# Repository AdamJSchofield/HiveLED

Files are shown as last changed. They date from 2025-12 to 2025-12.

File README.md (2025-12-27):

# HiveLED

Hexagonal LED matrix display with 107 individually addressable LEDs (SK9822-A), onboard ESP32-S3 MCU, buck converter, current/temperature monitoring, and PWM fan headers with 40x80mm board area reserved for an optional heatsink. Designed to be compatible with WLED. Multiple panels can be chained together and driven by a single 9-24V power supply. LED display input can be controlled by the onboard MCU, received over a network, or hard wired with onboard JST connectors.

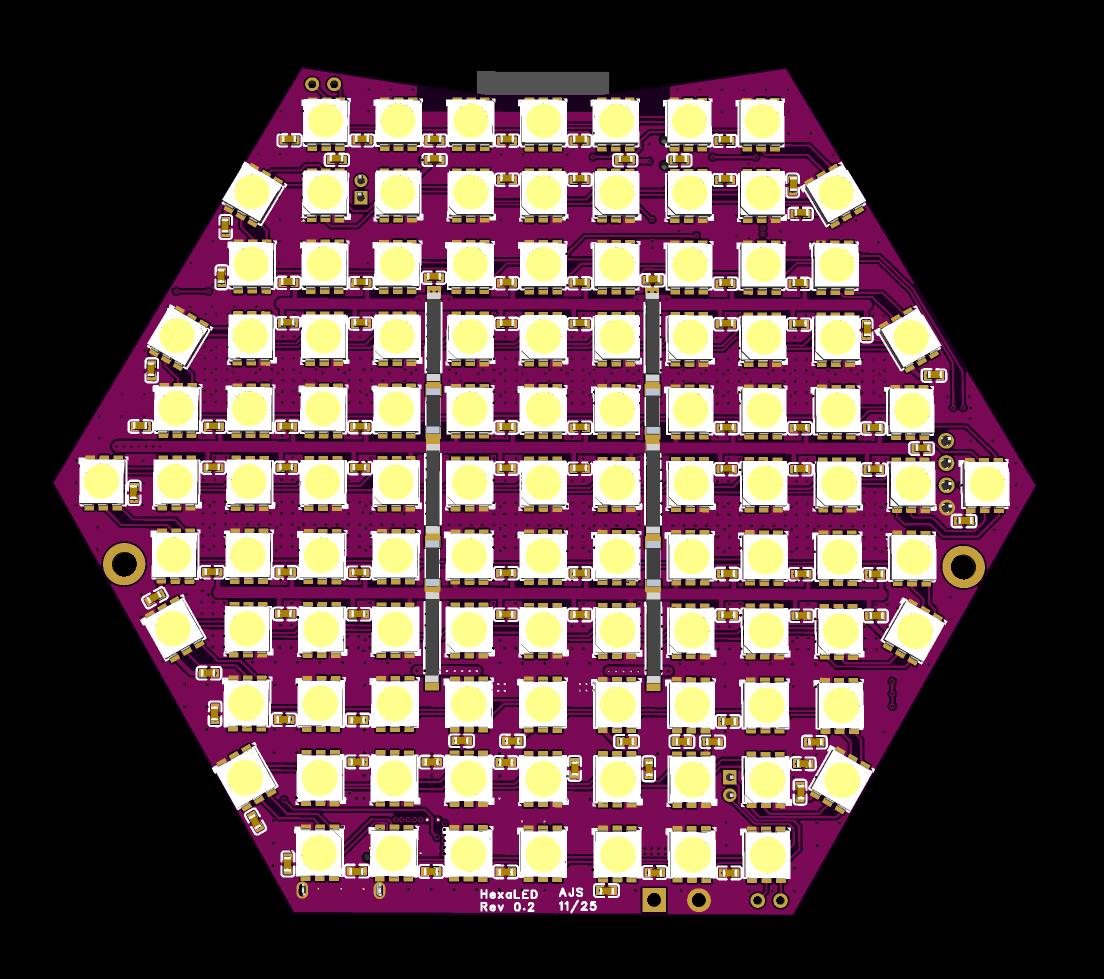
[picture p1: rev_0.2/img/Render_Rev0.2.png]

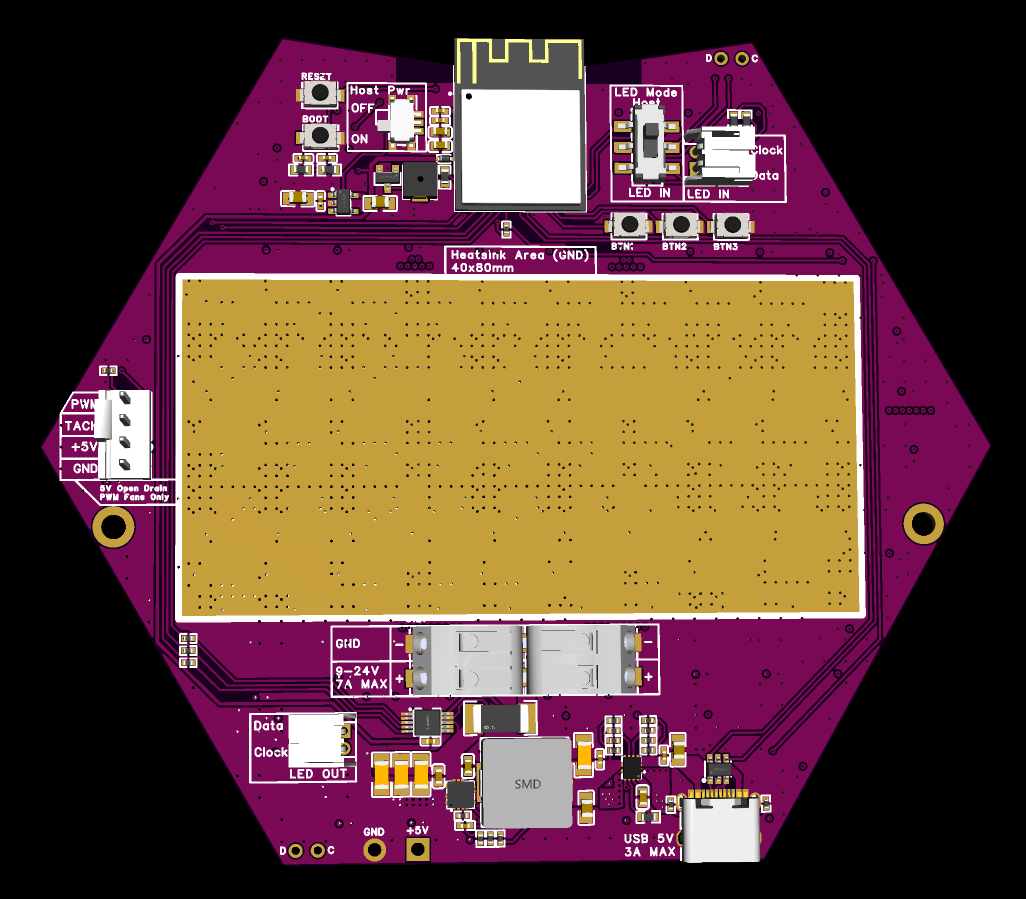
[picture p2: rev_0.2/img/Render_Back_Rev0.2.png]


## Specs
- 107x SK9822-A LEDs (max 55mA each)
- Max power consumption: 28W
- Min input voltage: 9V
- Max input voltage: 24V

## Warning

Dense LED matrix displays like this one have the potential to generate A LOT of heat. With all safety limits disabled at full brightness, these LEDs can produce enough heat to cause a catastrophic meltdown.

Managing Heat:
- Use the "Current Limiter" feature of WLED. 2000mA is a reasonable limit. This is only a soft limit for the brightness control based on estimated current by WLED. The brightness slider in WLED is scaled by a factor of ```(WLED Current Limit/Potential MAX Current)```. IMPORTANT: The INA228 current displayed in WLED when using the usermod is the current of the input power supply inclusive of all components at the input power supply voltage. The "Estimated Current" in vanilla WLED is only an estimate of the current drawn by the LEDs at 5V. When using a 12V power supply, the estimated current in WLED will indicate higher than the INA228 current because ```Current = Voltage / Resistance (load)```, often defined as V=IR.
- Use the INA228 Usermod and configure emergency shutoff based on over-temperature or over-power conditions. 70C is a good temperature limit for enclosures printed in PETG. 
- Use a 5V PWM fan and 40x80mm heatsink to dissipate heat more effectivley. The recommended fan is a Noctua NF-A4x10 5V PWM. One, or two with a 4-pin splitter. 40x40mm or 40x80mm heatsinks are commonly available online. A PWM fan and aluminum heatsink can reduce the max temperature of the board at 50% brightness by 15C. This can help extend the life of the LEDs or enable higher current/brightness limits.

## WLED Setup

https://kno.wled.ge/

### LED Settings

- LED Type: APA102 (similar timings to SK9822)
- Clock Speed: Fastest
- Num LEDs: 107
- Data Pin: 35
- Clock Pin: 36
- Button 1 Pin: 47
- Button 2 Pin: 33
- Button 3 Pin: 34

### INA228 Usermod
The HiveLED matrix contains an onboard INA228 IC for monitoring the temperature of the PCB and real-time power consumption. These features provide additional diagnostic information and can be used as an electronic fuse as a backup to the "soft" current limiter built into WLED. These features also enable automatic temperature control with a 5V PWM fan and optional heatsink. Accurate temperature monitoring and configurable emergency shutoff functions protect the (most likely 3D printed) enclosure, extend the life of the components, and reduce the risk of catastrophic failure.

I will submit a pull request to add the INA228 usermod to WLED soon. To build your own binaries that include support for the INA228 features, see my fork of the WLED repo.

### Usermod Pin Settings

Config > Usermods

- Global I2C SDA Pin: 15
- Global I2C SCL Pin: 14
- INA228 Alert Pin: 16
- Fan PWM Pin: 12
- Fan Tach Pin: 13
- Buzzer Pin: 9

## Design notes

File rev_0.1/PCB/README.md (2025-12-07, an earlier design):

## Description
A bare-bones hexagon-shaped LED panel with recillinear LED spacing. Uses SK9822-A LEDS in a 4-wire serial configuration and serpentine routing. Can be manufactured with a single copper layer on PCB materials such as aluminum for better heat dissipation. Clock and Data input pins are positioned at the top of the board with daisy-chainable outputs at the bottom. Similarly, there are two contacts for 5V and GND on each end of the board.

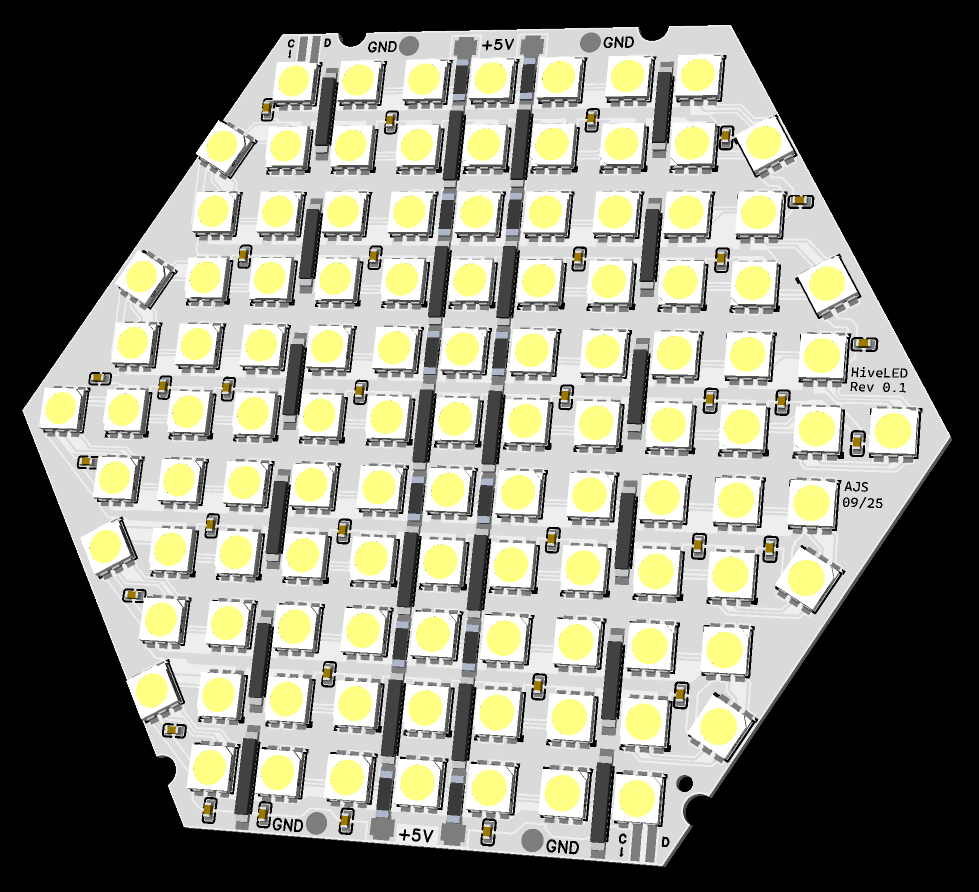
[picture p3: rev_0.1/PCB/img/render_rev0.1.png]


## Specifications
- 107x SK9822-A LEDs
- 5V operating voltage
- 2mm-pitch solderable pads for Clock and Data signal lines (input and output)
- 0-ohm jumpers for clean power traces and low-impedence return path to ground

## Caution
With all onboad LEDs set to full bright white, the total current draw of the panel can be up to 5.5A! Even on aluminium substrate, this is far too much power for the small board to dissipate safely. 5V fans or heatsinks can be attached to the back of the aluminum board for better heat distribution and the ability to run brighter for longer without overheating.

Use caution and limit the current draw to 2-3A in firmware when possible and avoid running the LEDs at full white for extended periods. Always use a physical fuse (2-3A) on the input power supply line to prevent hardware failures or firmware glitches from exceeding the recomended current draw and safety margins.

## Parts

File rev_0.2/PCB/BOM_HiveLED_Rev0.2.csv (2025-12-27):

No. | Quantity | Comment | Designator | Footprint | Value | Manufacturer Part | Manufacturer | Supplier Part | Supplier
1 | 5 | TS-1088-AR02016 | BOOT,BTN1,BTN2,BTN3,RESET | SW-SMD_L3.9-W3.0-P4.45 |  | TS-1088-AR02016 | XUNPU(讯普) | C720477 | LCSC
2 | 1 | 4kHz | BUZZER1 | BUZ-SMD_L4.0-W4.0-P3.50-L | 4kHz | FUET-4020 | FUET(福声科技) | C391027 | LCSC
3 | 97 | 1uF | C1,C2,C3,C4,C5,C6,C7,C8,C9,C10,C11,C12,C13,C14,C15,C16,C17,C18,C19,C20,C21,C22,C23,C24,C25,C26,C27,C28,C30,C31,C33,C34,C35,C36,C37,C38,C39,C41,C42,C44,C45,C46,C47,C48,C49,C50,C51,C53,C54,C56,C57,C58,C59,C60,C61,C62,C63,C64,C66,C67,C69,C70,C71,C72,C73,C74,C75,C77,C79,C80,C82,C83,C84,C85,C86,C87,C88,C89,C90,C91,C92,C93,C94,C95,C96,C97,C98,C99,C100,C101,C102,C103,C104,C105,C106,C107,C143 | C0603 | 1uF | CL10B105KA8NNNC | SAMSUNG(三星) | C29936 | LCSC
4 | 4 | 10uF | C108,C109,C155,C156 | C0805 | 10uF | CL21B106KOQNNNE | SAMSUNG(三星) | C95841 | LCSC
5 | 2 | 10uF | C112,C113 | C0603 | 10uF | CL10A106MA8NRNC | SAMSUNG(三星) | C96446 | LCSC
6 | 1 | 1uF | C114 | C0402 | 1uF | CL05A105KA5NQNC | SAMSUNG(三星) | C52923 | LCSC
7 | 2 | 100nF | C115,C119 | C0402 | 100nF | CL05B104KO5NNNC | SAMSUNG(三星) | C1525 | LCSC
8 | 1 | 1uF | C118 | C0402 | 1uF | CL05A105KO5NNNC | SAMSUNG(三星) | C29266 | LCSC
9 | 4 | 100nF | C136,C153,C154,C157 | C0402 | 100nF | CL05B104KB54PNC | SAMSUNG(三星) | C307331 | LCSC
10 | 3 | 4.7uF | C146,C147,C148 | C1206 | 4.7uF | 1206B475K500NT | FH(风华) | C29823 | LCSC
11 | 2 | 100nF | C149,C150 | C0603 | 100nF | CC0603KRX7R9BB104 | YAGEO(国巨) | C14663 | LCSC
12 | 1 | 47uF | C151 | C1206 | 47uF | CL31A476MPHNNNE | SAMSUNG(三星) | C96123 | LCSC
13 | 1 | 100pF | C152 | C0402 | 100pF | 0402CG101J500NT | FH(风华) | C1546 | LCSC
14 | 1 | 470531000 | CN2 | CONN-TH_47053-1000 |  | 470531000 | MOLEX | C240840 | LCSC
15 | 1 | RB521S30T1G | D4 | SOD-523_L1.2-W0.8-LS1.6-RD |  | RB521S30T1G | onsemi(安森美) | C145179 | LCSC
16 | 1 | USBLC6-2SC6 | D5 | SOT-23-6_L2.9-W1.6-P0.95-LS2.8-BL |  | USBLC6-2SC6 | ST(意法半导体) | C7519 | LCSC
17 | 1 | 3.3uH | L1 | IND-SMD_L10.2-W10.2-LS10.8 | 3.3uH | IHLP4040DZER3R3M01 | VISHAY(威世) | C845075 | LCSC
18 | 1 | XC6220B331MR-G | Q1 | SOT-25_L3.0-W1.6-P0.95-LS2.8-TL |  | XC6220B331MR-G | TOREX(特瑞仕) | C86534 | LCSC
19 | 1 | MMBT2222ALT1G | Q2 | SOT-23-3_L2.9-W1.3-P1.90-LS2.4-BR |  | MMBT2222ALT1G | onsemi(安森美) | C82460 | LCSC
20 | 4 | HoTCu-5.2C-0R | R5,R6,R7,R8 | RES-SMD_L5.2-W1.5_C9900027771 |  | HoTCu-5.2C-0R | Milliohm(毫欧) | C5367526 | LCSC
21 | 6 | 0Ω | R15,R16,R17,R18,R19,R20 | RES-SMD_L10.2-W1.5_HOTCU-10.2D-0R | 0Ω | HoTCu-10.2D-0R | Milliohm(毫欧) | C5127898 | LCSC
22 | 2 | 10kΩ | R55,R56 | R0603 | 10kΩ | 0603WAF1002T5E | UNI-ROYAL(厚声) | C25804 | LCSC
23 | 1 | 180Ω | R66 | R0603 | 180Ω | 0603WAF1800T5E | UNI-ROYAL(厚声) | C22828 | LCSC
24 | 1 | 15mΩ | R76 | RES-SMD_L6.4-W3.2-R2512 | 15mΩ | HoLLR2512-3W-15mR-1% | Milliohm(毫欧) | C2985715 | LCSC
25 | 2 | 5.1kΩ | R92,R93 | R0402 | 5.1kΩ | 0402WGF5101TCE | UNI-ROYAL(厚声) | C25905 | LCSC
26 | 2 | 23.7kΩ | R97,R103 | R0402 | 23.7kΩ | RC-02K2372FT | FH(风华) | C453604 | LCSC
27 | 5 | 5kΩ | R98,R99,R100,R102,R104 | R0402 | 5kΩ | RC0402FR-075KL | YAGEO(国巨) | C477765 | LCSC
28 | 7 | 10kΩ | R101,R110,R115,R120,R126,R127,R128 | R0402 | 10kΩ | 0402WGF1002TCE | UNI-ROYAL(厚声) | C25744 | LCSC
29 | 1 | 22kΩ | R105 | R0603 | 22kΩ | 0603WAF2202T5E | UNI-ROYAL(厚声) | C31850 | LCSC
30 | 2 | 200Ω | R106,R107 | R0603 | 200Ω | 0603WAF2000T5E | UNI-ROYAL(厚声) | C8218 | LCSC
31 | 1 | 100kΩ | R111 | R0402 | 100kΩ | 0402WGF1003TCE | UNI-ROYAL(厚声) | C25741 | LCSC
32 | 1 | 20kΩ | R112 | R0402 | 20kΩ | 0402WGF2002TCE | UNI-ROYAL(厚声) | C25765 | LCSC
33 | 1 | 73.2kΩ | R114 | R0402 | 73.2kΩ | RT0402BRD0773K2L | YAGEO(国巨) | C852909 | LCSC
34 | 1 | MST22D18G2 | SW4 | SW-SMD_MST22D18G2 |  | MST22D18G2 | SHOU HAN(首韩) | C431544 | LCSC
35 | 1 | MINI MSK12CO2 | SW5 | SW-SMD_MSK12CO2 |  | MINI MSK12CO2 | SHOU HAN(首韩) | C2681570 | LCSC
36 | 107 | SK9822-A | U1,U2,U3,U4,U5,U6,U7,U8,U9,U10,U11,U12,U13,U14,U15,U16,U17,U18,U19,U20,U21,U22,U23,U24,U25,U26,U27,U28,U29,U30,U31,U32,U33,U34,U35,U36,U37,U38,U39,U40,U41,U42,U43,U44,U45,U46,U47,U48,U49,U50,U51,U52,U53,U54,U55,U56,U57,U58,U59,U60,U61,U62,U63,U64,U65,U66,U67,U68,U69,U70,U71,U72,U73,U74,U75,U76,U77,U78,U79,U80,U81,U82,U83,U84,U85,U86,U87,U88,U89,U90,U91,U92,U93,U94,U95,U96,U97,U98,U99,U100,U101,U102,U103,U104,U105,U106,U107 | LED-SMD_6P-L5.0-W5.0-P1.60-LS5.4-TL_SK9822 |  | SK9822-A | 欧思科光电 | C5378730 | LCSC
37 | 2 | S2B-PH-K-S(LF)(SN) | U122,U123 | CONN-TH_S2B-PH-K-S-LF-SN |  | S2B-PH-K-S(LF)(SN) | JST | C173752 | LCSC
38 | 2 | 2060-452/998-404 | U126,U127 | CONN-SMD_2060-452 |  | 2060-452/998-404 | WAGO(万可) | C2765055 | LCSC
39 | 1 | INA228AQDGSRQ1 | U129 | VSSOP-10_L3.0-W3.0-P0.50-LS4.9-BL |  | INA228AQDGSRQ1 | TI(德州仪器) | C5214669 | LCSC
40 | 1 | TPS2121RUXR | U130 | VQFN-HR-12_L2.5-W2.0-P0.50-BL |  | TPS2121RUXR | TI(德州仪器) | C485916 | LCSC
41 | 1 | TPS56637RPAR | U136 | VQFN-HR-10_L3.0-W3.0_RPA |  | TPS56637RPAR | TI(德州仪器) | C841386 | LCSC
42 | 1 | 2.4GHz | U137 | BULETM-SMD_ESP32-S3-MINI-1-N8 | 2.4GHz | ESP32-S3-MINI-1-N8 | ESPRESSIF(乐鑫) | C2913206 | LCSC
43 | 1 | TYPE-C-31-M-12 | USBC1 | USB-C_SMD-TYPE-C-31-M-12_1 |  | TYPE-C-31-M-12 | 韩国韩荣 | C165948 | LCSC

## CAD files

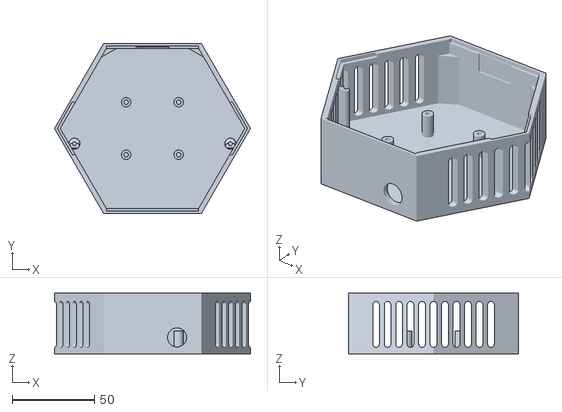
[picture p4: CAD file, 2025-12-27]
rev_0.2/Models/HiveLED_Rev0.2_Case_40x40Fan.stl
119.4 x 103.4 x 37.0

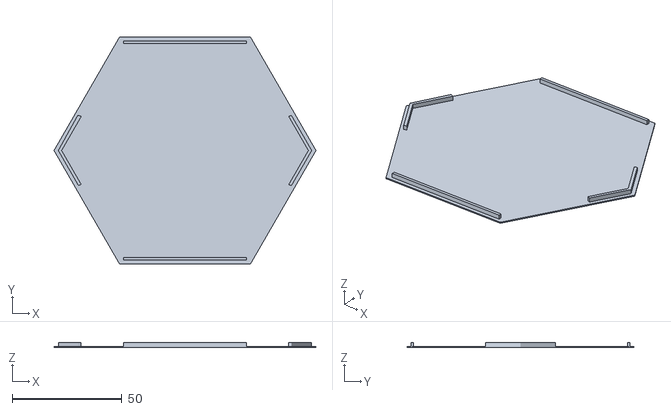
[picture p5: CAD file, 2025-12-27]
rev_0.2/Models/HiveLED_Rev0.2_Diffuser1.stl
119.4 x 103.4 x 2.40

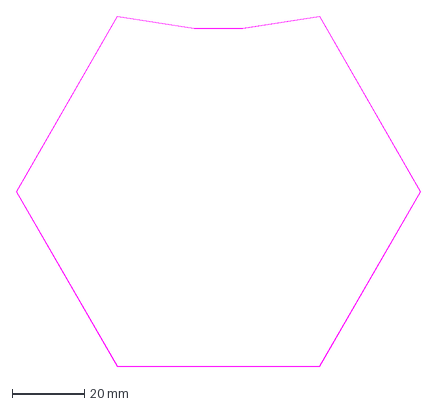
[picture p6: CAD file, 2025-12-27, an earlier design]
rev_0.1/PCB/Outline.dxf
112.1 x 97.1 mm

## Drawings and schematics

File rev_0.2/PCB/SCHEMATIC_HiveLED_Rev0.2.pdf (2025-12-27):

# 107 SK9822-A LEDs Serpentine Routing

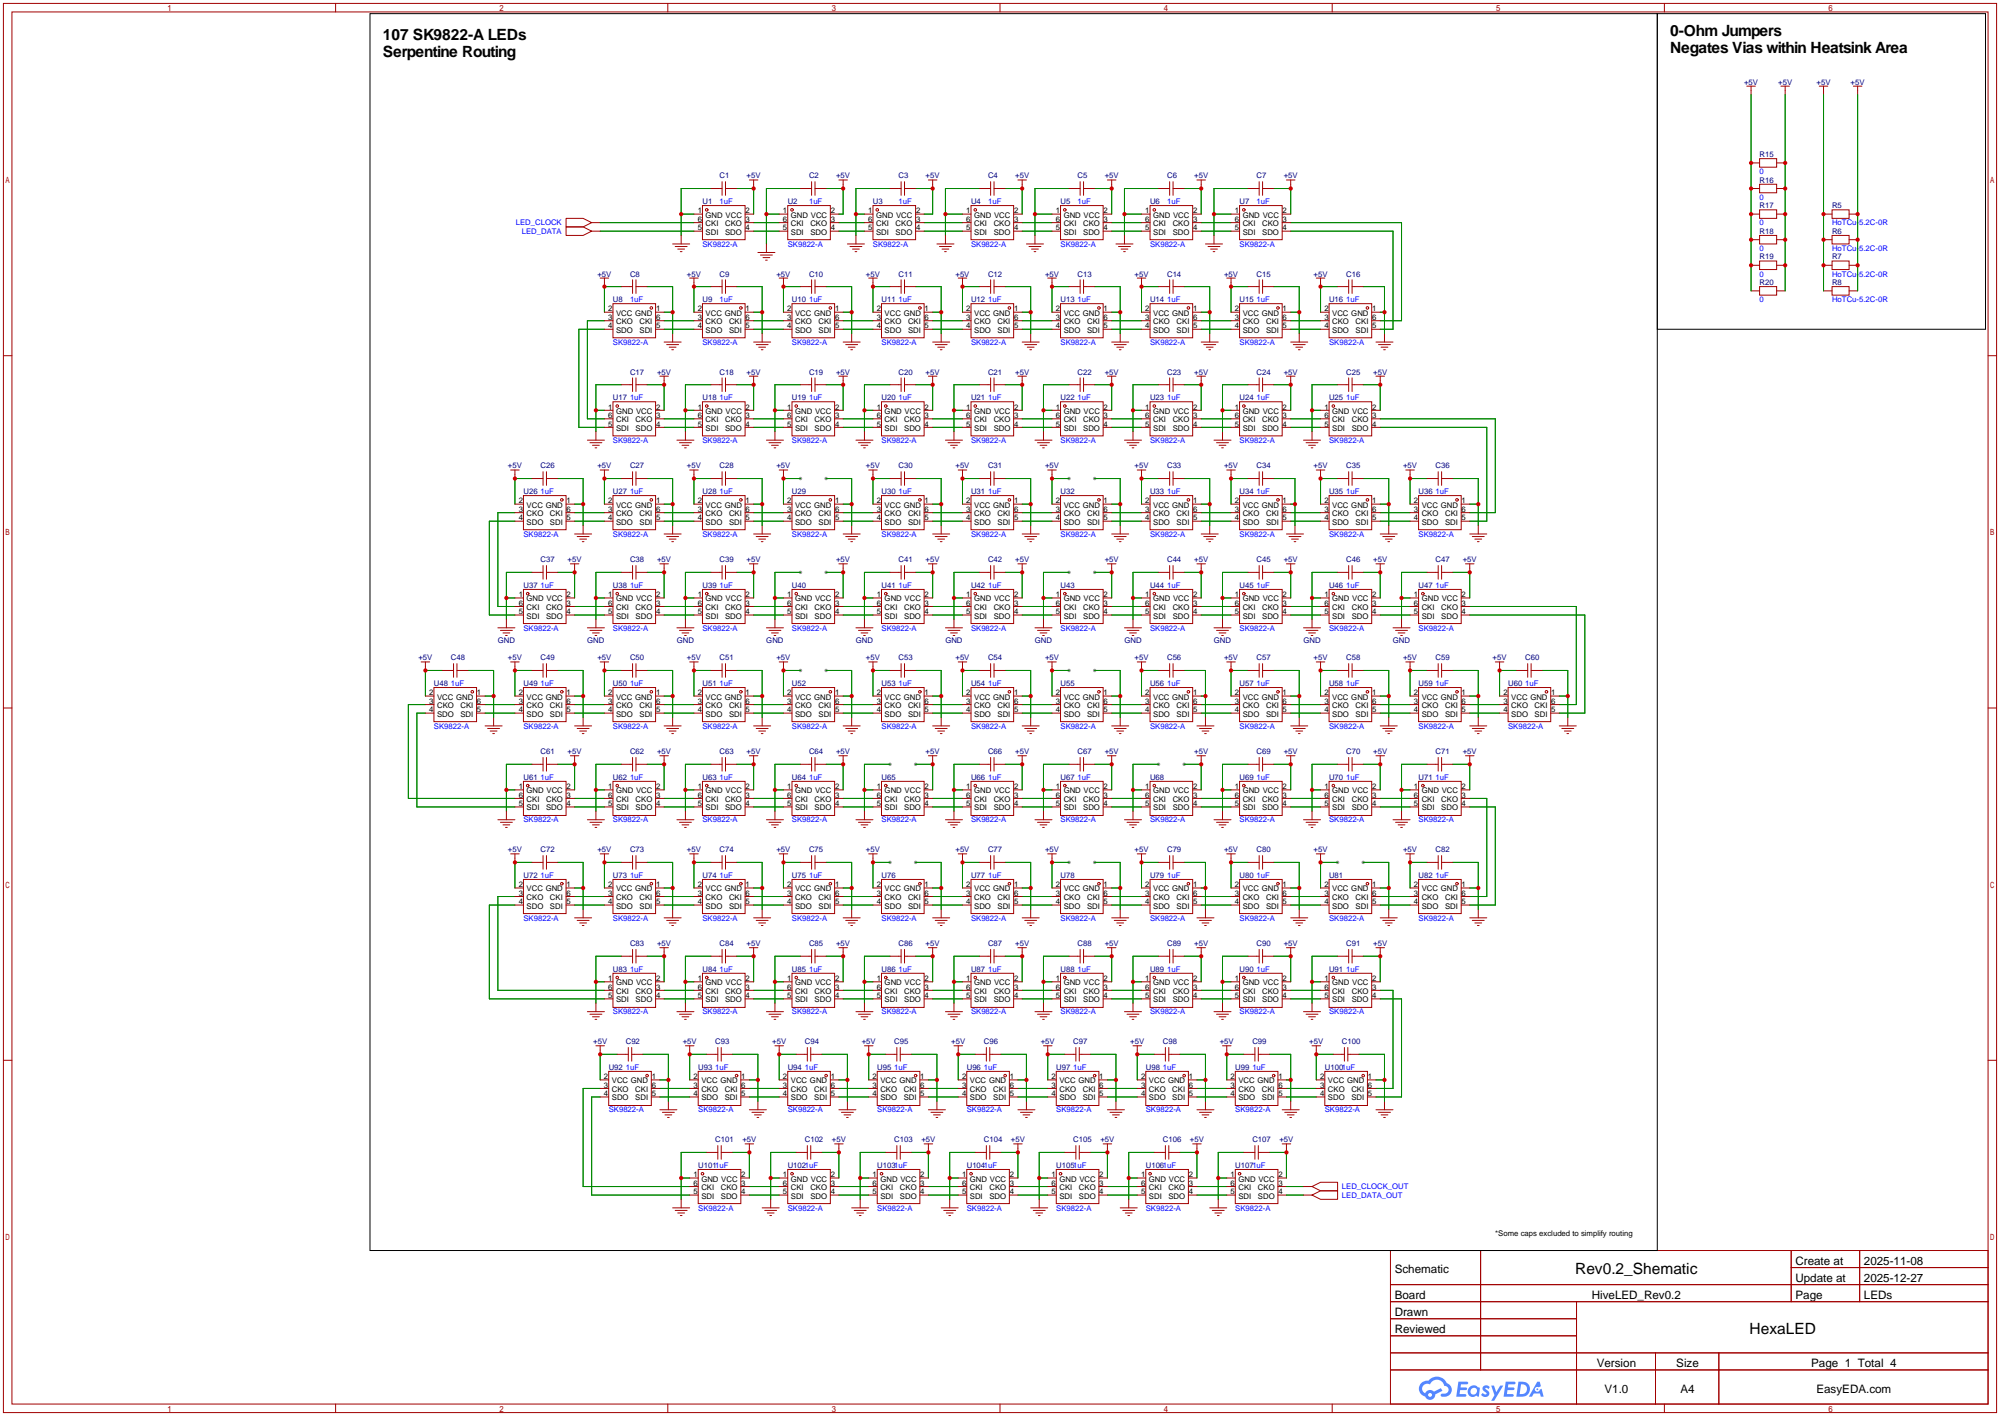
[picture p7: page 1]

0-Ohm Jumpers
Negates Vias within Heatsink Area

*Some caps excluded to simplify routing

Schematic | Rev0.2_Shematic | Create at | 2025-11-08

Update at | 2025-12-27

Board | HiveLED_Rev0.2 | Page | LEDs
Drawn | | HexaLED
Reviewed

Version | Size | Page 1 Total 4
V1.0 | A4 | EasyEDA.com

IO48 30 | IO35 31 IO36 32 IO37 33 IO38 34 IO39 35 IO40 36 IO41 37 IO42 38 TXD0 39 RXD0 40 IO45 41 GND 42 GND 43 IO46 44 EN 45 GND 46 GND 47 GND 48 GND 49 GND 50 GND 51 GND 52 GND 53 GND 54 GND 55 GND 56 GND 57 GND 58 GND 59 GND 60 GND
ESP32-S3-MINI-1-N8 | USB-C

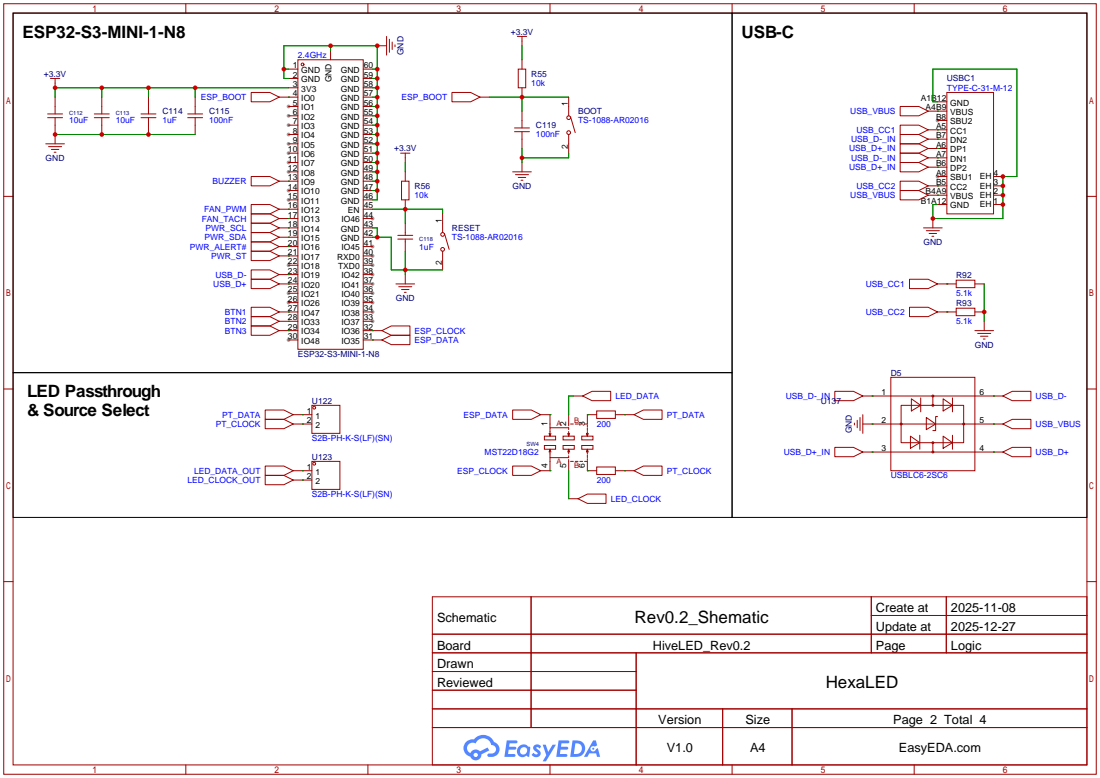
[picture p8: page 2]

Schematic | Rev0.2_Shematic | Create at | 2025-11-08

Update at | 2025-12-27

Board | HiveLED_Rev0.2 | Page | Logic
Drawn | | HexaLED
Reviewed

# Buck Regulator (9-24V) -> 5V Current/Temperature Monitor

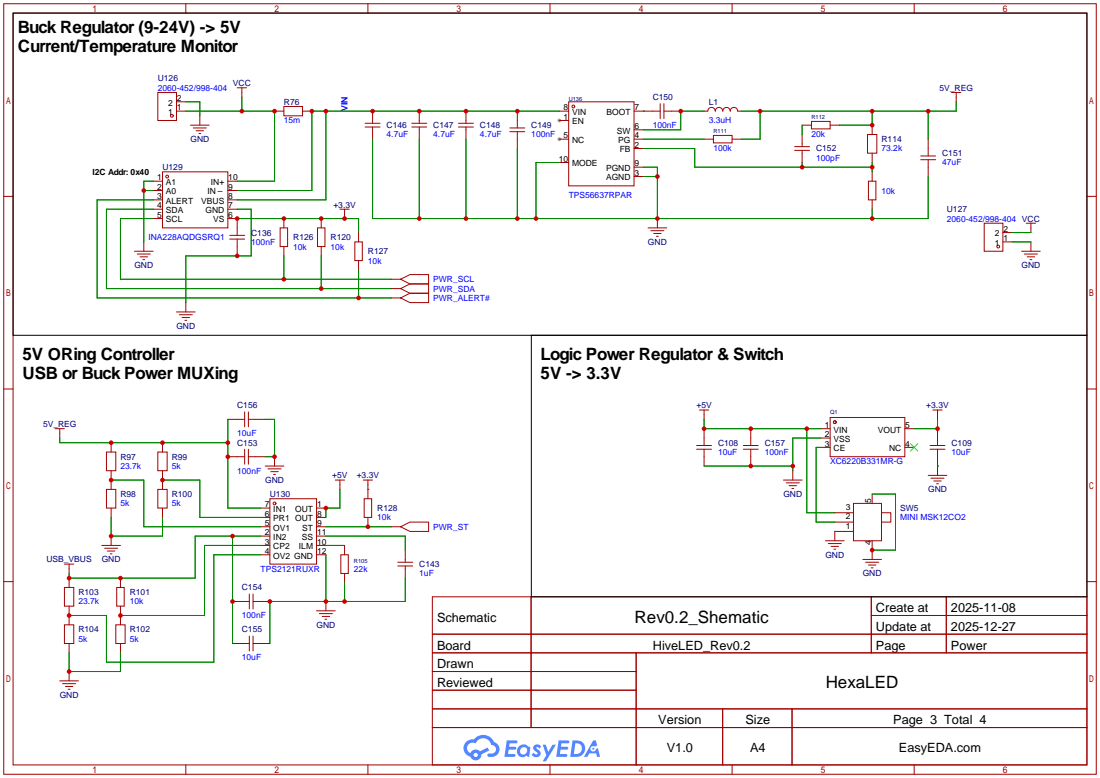
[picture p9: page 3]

5V ORing Controller
USB or Buck Power MUXing

Logic Power Regulator & Switch

Schematic | Rev0.2_Shematic | Create at | 2025-11-08

Board | HiveLED_Rev0.2 | Page | Power
Drawn | | HexaLED
Reviewed

5V PWM Fan Header | Piezo Buzzer

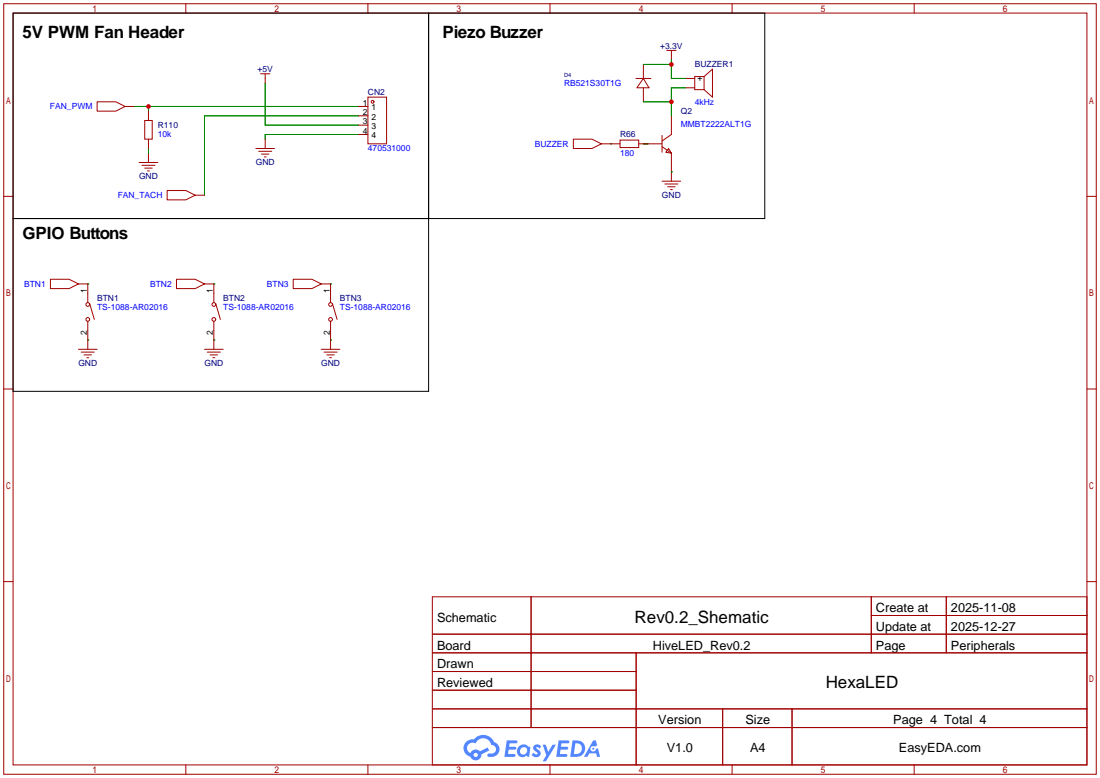
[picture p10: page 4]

Schematic | Rev0.2_Shematic | Create at | 2025-11-08

Update at | 2025-12-27

Board | HiveLED_Rev0.2 | Page | Peripherals
Drawn | | HexaLED
Reviewed

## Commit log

2025-12-07 Init Rev0.1
    [HiveLED_rev0.1_bom.csv, HiveLED_rev0.1_pp.xlsx]
2025-12-27 Update PCB Files
    [BOM_HiveLED_Rev0.2.csv, HiveLED_Rev0.2_Case_40x40Fan.stl, HiveLED_Rev0.2_Diffuser1.stl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]
